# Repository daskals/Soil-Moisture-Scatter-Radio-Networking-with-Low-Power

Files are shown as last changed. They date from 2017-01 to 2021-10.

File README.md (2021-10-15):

# Soil-Moisture-Scatter-Radio-Networking-with-Low-Power
Hardware and Software files of  IEEE publication: Soil Moisture Scatter Radio Networking with Low Power

In this repo, a low-cost (6 Euro per sensor), low-power (in the order of 200 µW per sensor), with high communication range (in the order of 250 meter), scatter radio sensor network is presented, for soil moisture monitoring at multiple locations. The proposed network utilizes analog frequency modulation (FM) in a bistatic network
architecture (i.e., the emitter and reader are not co-located), while
the sensors operate simultaneously, using frequency division
multiple access (FDMA). In contrast to prior art, this work
utilizes an ultra-low cost software-defined radio reader, offers
custom microstrip capacitive sensing with simple calibration, as
well as modulation pulses for each scatter radio sensor with
50% duty cycle; the latter is necessary for scalable network
designs. Overall root mean squared error (RMSE) below 1% is observed, even for ranges of 250 m. This is another small (but concrete) step for the adoption of scatter radio technology as a
key enabling technology for scalable, large-scale, low-power and cost environmental sensor networking.
---

IEEE Xplore: https://ieeexplore.ieee.org/document/7490345/ \
Local: http://www.daskalakispiros.com/files/daskalakis_mtt_2015.pdf

---
**Questions/issues**
Inquiries regarding the scripts provided are cordially welcome.

---
**Citing**

If you use our algorithm, please cite [[1]](https://ieeexplore.ieee.org/document/7490345/).

```bibtex
@article{daskalakis2016soil,
  title={Soil moisture scatter radio networking with low power},
  author={Daskalakis, Spyridon-Nektarios and Assimonis, Stylianos D and Kampianakis, Eleftherios and Bletsas, Aggelos},
  journal={IEEE Transactions on Microwave Theory and Techniques},
  volume={64},
  number={7},
  pages={2338--2346},
  year={2016},
  publisher={IEEE}
}
 
```

[[1]](https://ieeexplore.ieee.org/document/7490345/) S. N. Daskalakis, S.D. Assimonis, E. Kampianakis and A. Bletsas, Soil Moisture Scatter Radio Networking with Low Power, IEEE Transactions on Microwave Theory and Techniques (TMTT), Special Issue on RFID Sensing & Imaging, Vol. 64, No. 7, pp. 2338-2346, July 2016.

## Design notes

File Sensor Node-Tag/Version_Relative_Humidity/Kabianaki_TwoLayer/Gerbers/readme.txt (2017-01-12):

File Description:

GTL: top copper
GBL: bottom copper
GTO: top silkscreen
GTP: top paste
GBO: bottom silkscreen
GTS: top solder mask
GBS: bottom solder mask
DRD: Drill file 1
Dri: Drill file 2

Solder Resist: YES
Silkscreen: NO
Non square: NO
2mm thick: NO
35u Copper: YES
SMD/GOLD: YES
<0.6mm: YES
Clearance < 10mil: YES
Test: NO

Delivery: 7 Days
Quantity: 45

Eleftherios Kampianakis
Tel: 6932702474
Office: 2821037426

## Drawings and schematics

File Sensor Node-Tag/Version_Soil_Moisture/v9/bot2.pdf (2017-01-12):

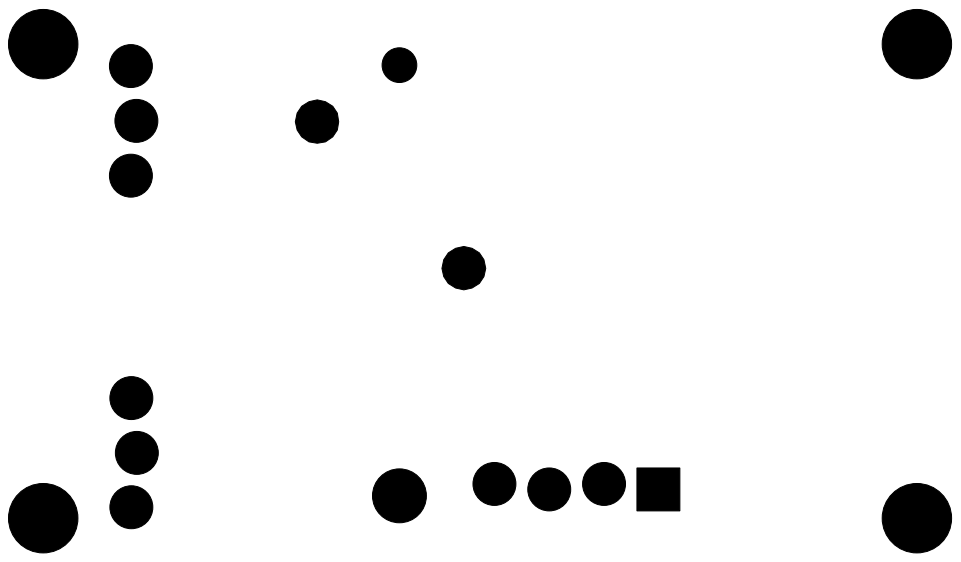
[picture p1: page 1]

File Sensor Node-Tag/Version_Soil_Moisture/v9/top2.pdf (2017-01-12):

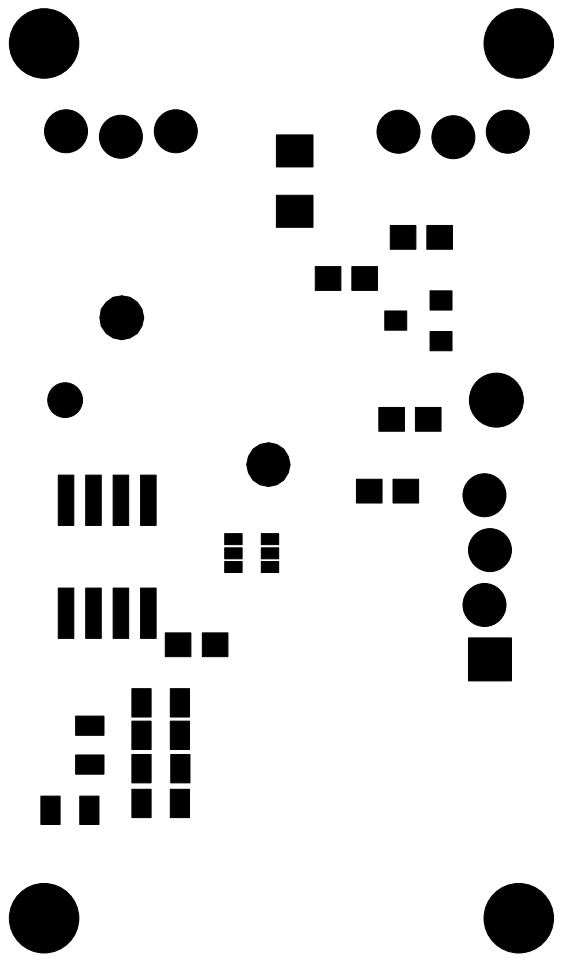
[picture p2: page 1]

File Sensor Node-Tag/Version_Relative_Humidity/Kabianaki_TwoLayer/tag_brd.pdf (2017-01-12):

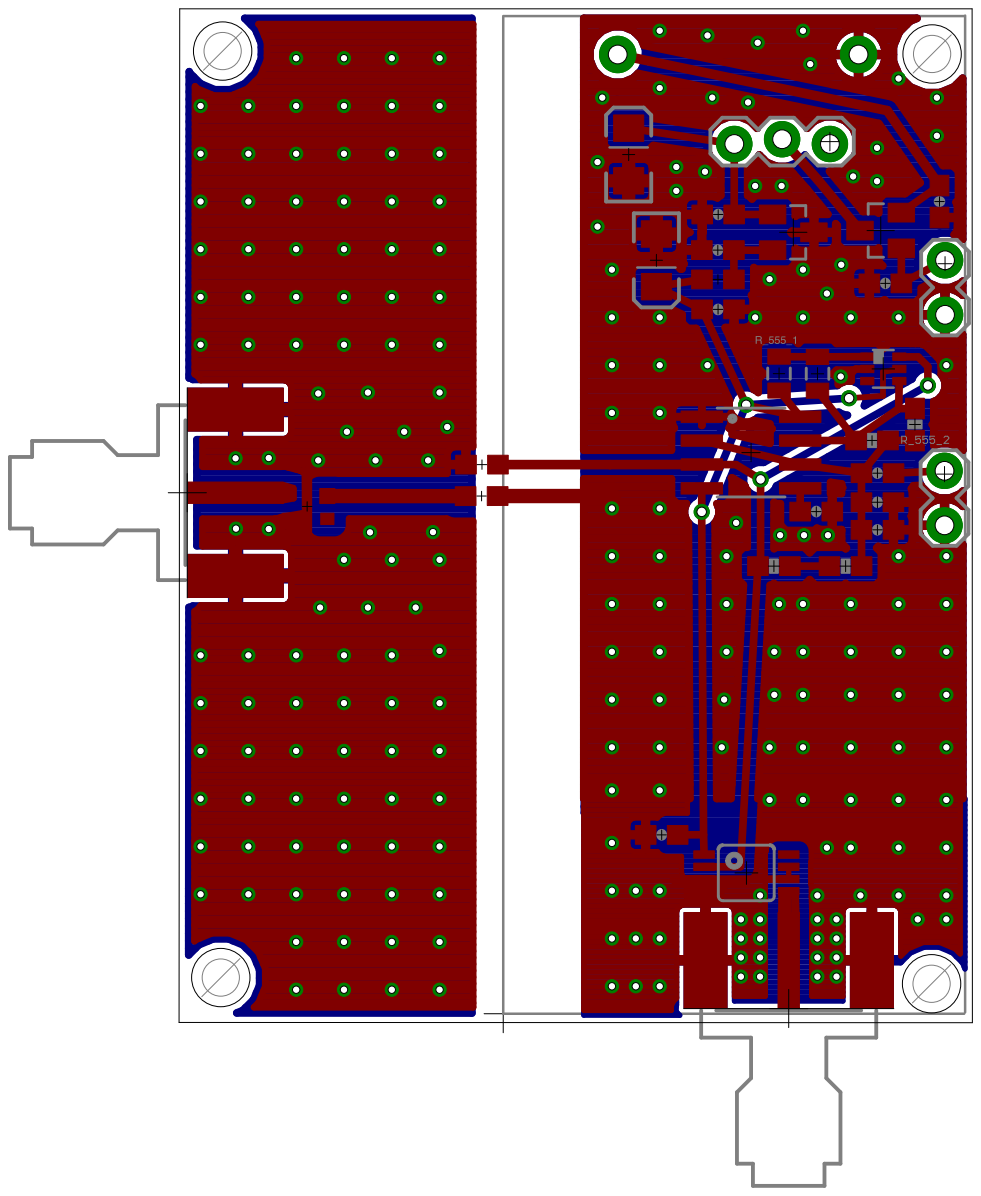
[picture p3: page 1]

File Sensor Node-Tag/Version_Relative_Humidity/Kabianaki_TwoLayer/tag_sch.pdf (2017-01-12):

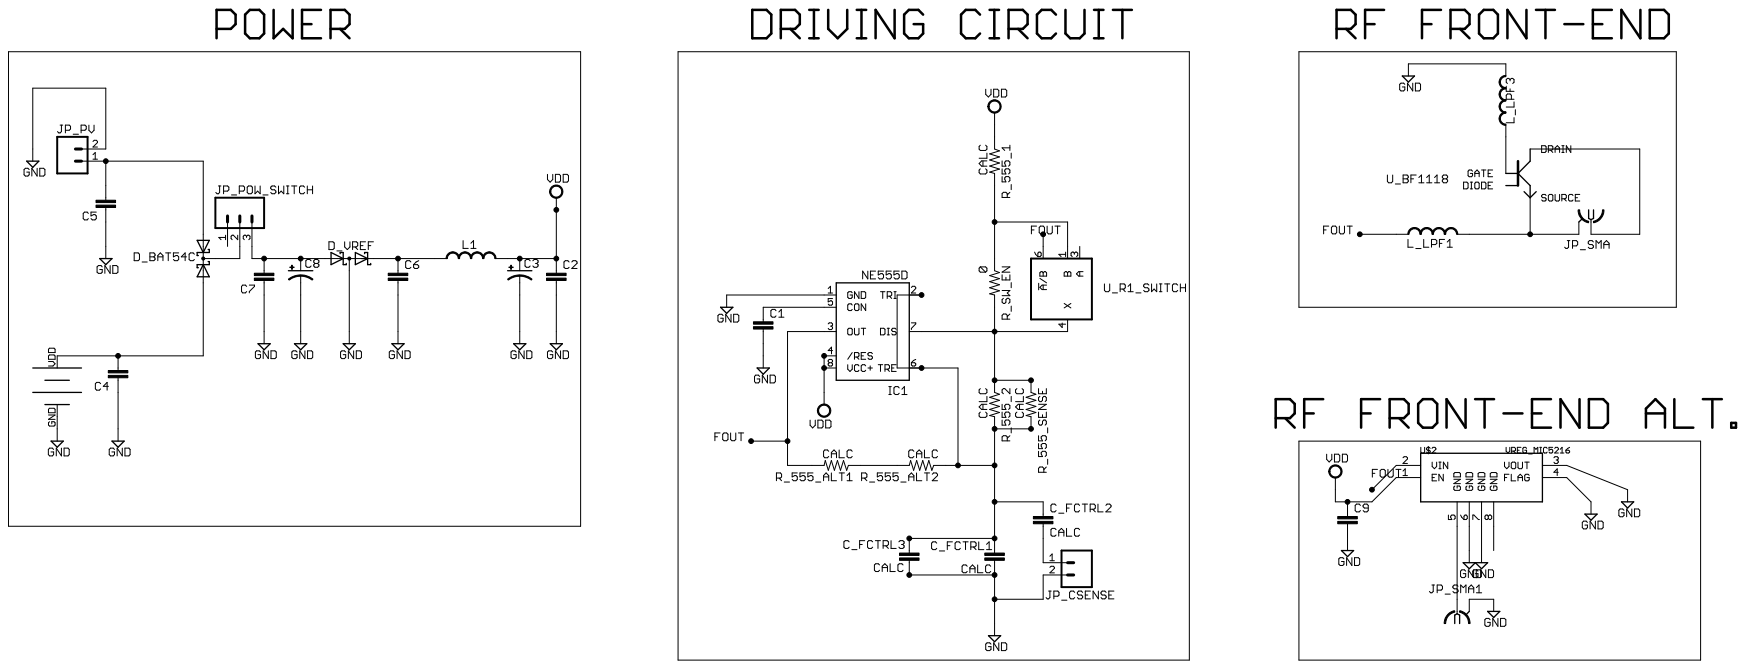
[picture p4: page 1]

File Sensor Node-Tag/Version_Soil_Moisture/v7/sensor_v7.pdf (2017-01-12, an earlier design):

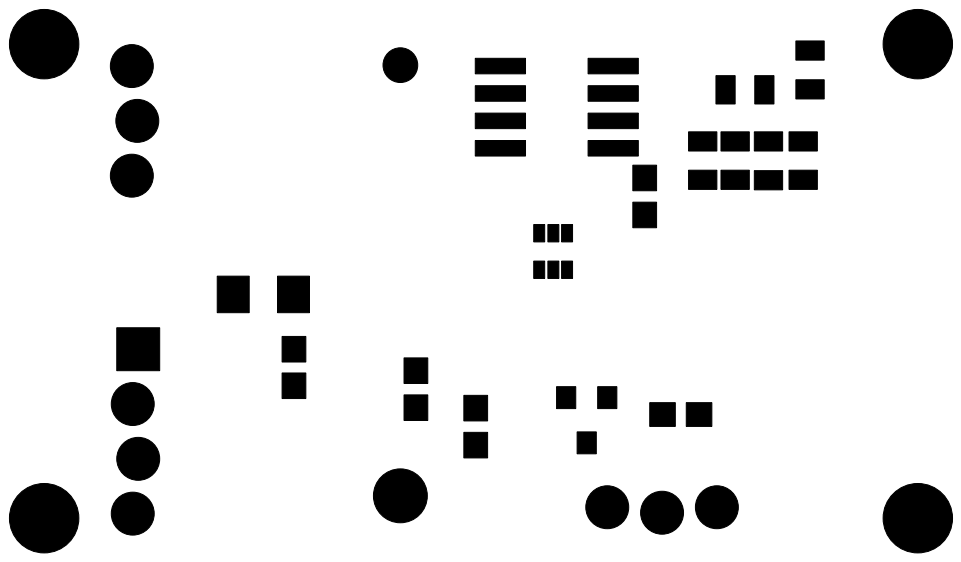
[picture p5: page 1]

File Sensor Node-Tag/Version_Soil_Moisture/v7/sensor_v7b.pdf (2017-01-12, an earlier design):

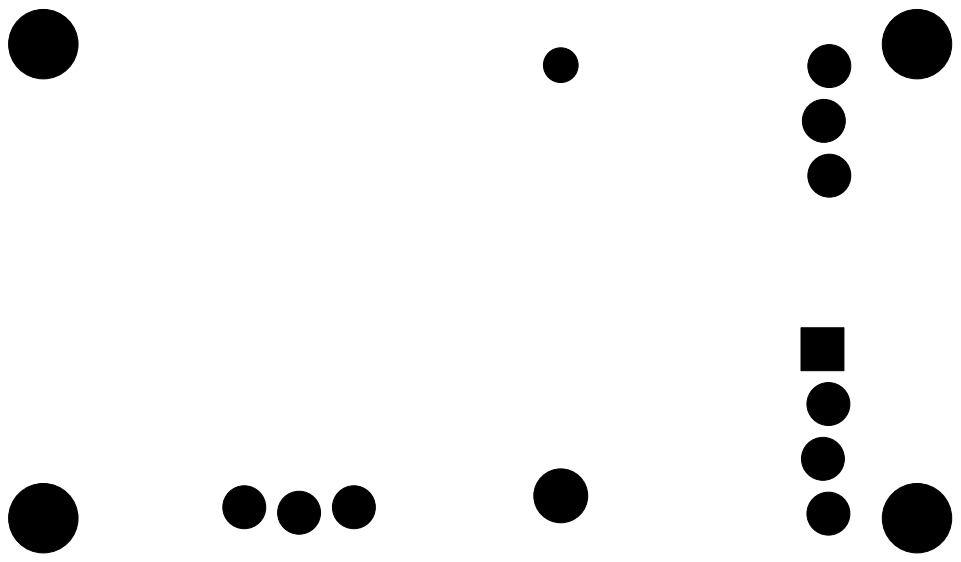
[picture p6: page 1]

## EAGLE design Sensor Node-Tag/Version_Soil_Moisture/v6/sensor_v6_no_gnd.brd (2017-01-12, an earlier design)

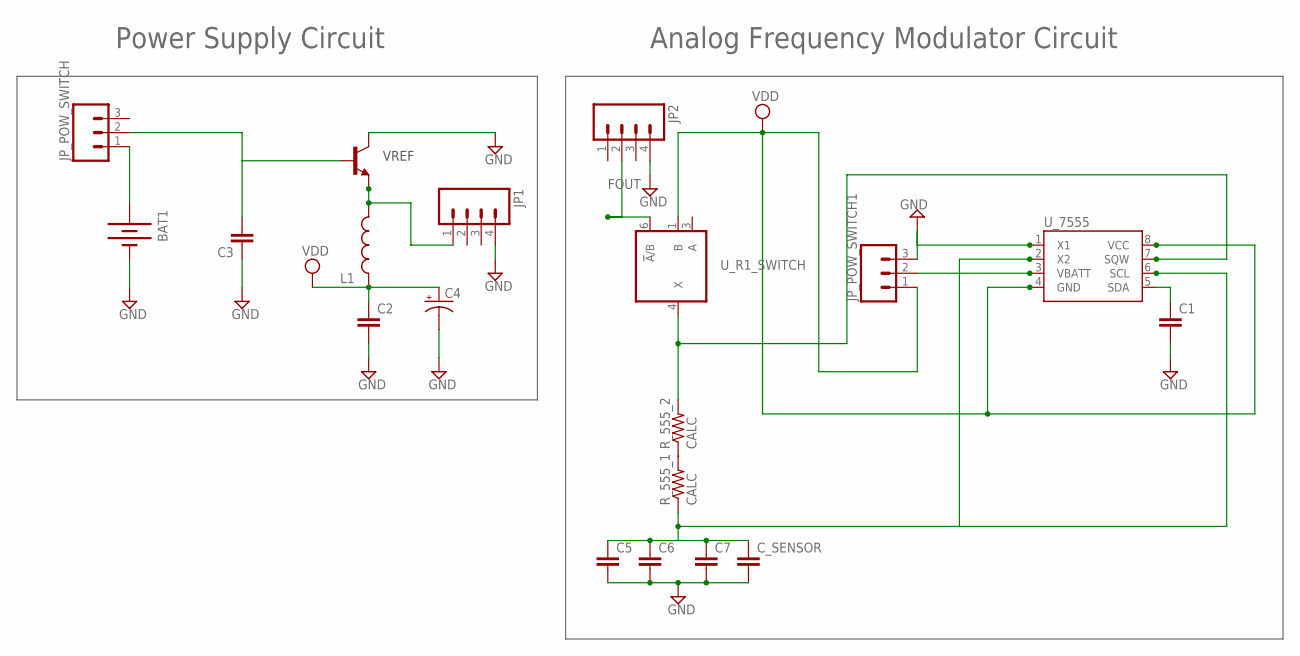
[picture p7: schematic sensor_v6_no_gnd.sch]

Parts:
BAT1: BATTERY20PTH_LAB; BATTCOM_20MM_PTH
C1, C2, C3: CAP0603-CAP; 0603-CAP
C4: CAP_POL1206; EIA3216
C5, C6, C7: CAP0805; 0805
C_SENSOR: CAP0805; 0805
JP1, JP2: M04LOCK; 1X04_LOCK
JP_POW_SWITCH, JP_POW_SWITCH1: M03LOCK; 1X03_LOCK
L1: INDUCTOR0603; 0603
R_555_1, R_555_2: CALC; 0805
U_7555: DS1307SO8; SO08
U_R1_SWITCH: 741G3157DCKR; DCK_R-PDSO-G6
U_VREF: TRANSISTOR_NPNSOT23-3; SOT23-3

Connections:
FOUT: JP2.2, JP_POW_SWITCH1.2, U_7555.3 (VBATT), U_R1_SWITCH.6 (!A!/B)
GND: BAT1.2 (-), C1.2, C2.2, C3.1, C4.C (-), C5.2, C6.2, C7.2, C_SENSOR.2, JP1.4, JP2.4, JP_POW_SWITCH1.3, U_7555.1 (X1), U_R1_SWITCH.2 (GND), U_VREF.3 (C)
unnamed: BAT1.1 (+), JP_POW_SWITCH.1
unnamed: R_555_1.2, R_555_2.1
P2: C5.1, C6.1, C7.1, C_SENSOR.1, R_555_1.1, U_7555.2 (X2), U_7555.6 (SCL)
P5: C1.1, U_7555.5 (SDA)
P7: R_555_2.2, U_7555.7 (SQW), U_R1_SWITCH.4 (X)
VCC: U_R1_SWITCH.5 (VCC)
VDD: C2.1, C4.A (+), JP_POW_SWITCH1.1, L1.1, U_7555.4 (GND), U_7555.8 (VCC), U_R1_SWITCH.1 (B)
VREFIN: C3.2, JP_POW_SWITCH.2, U_VREF.1 (B)
VREFOUT: JP1.1, L1.2, U_VREF.2 (E)

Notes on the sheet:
Power Supply Circuit
Analog Frequency Modulator Circuit
VREF

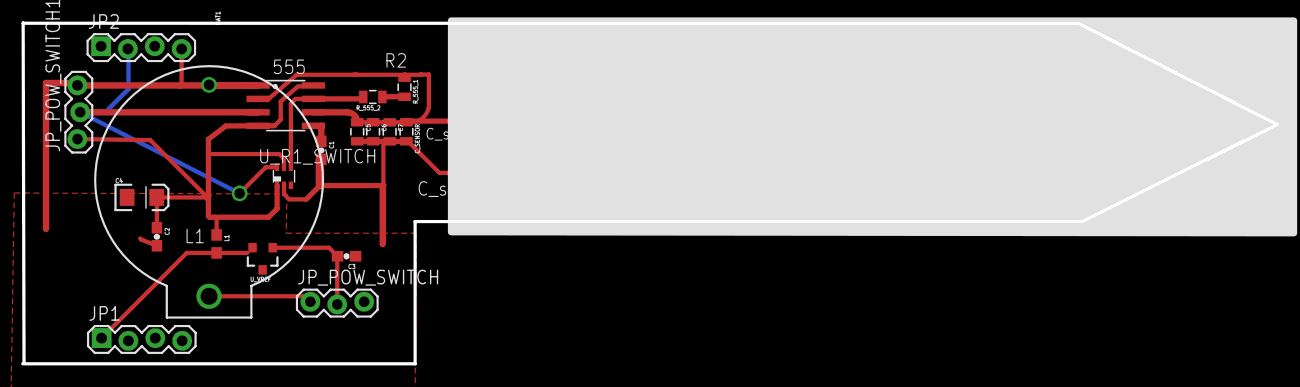
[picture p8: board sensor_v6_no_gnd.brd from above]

Board: 2 copper layers, 118.6 x 32.2 mm, 19 parts (0 on the bottom side), 10 nets.

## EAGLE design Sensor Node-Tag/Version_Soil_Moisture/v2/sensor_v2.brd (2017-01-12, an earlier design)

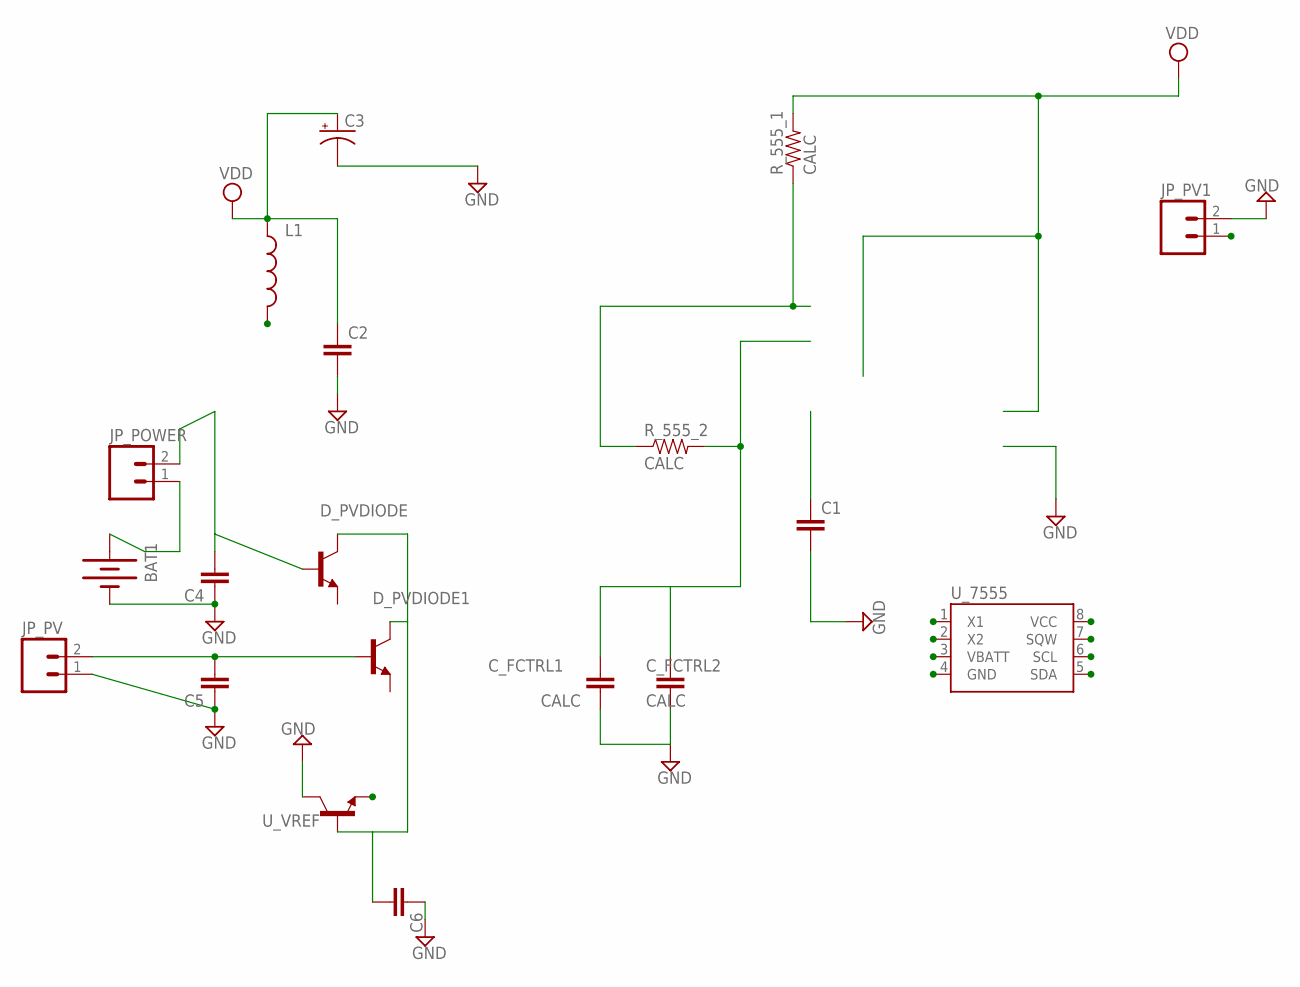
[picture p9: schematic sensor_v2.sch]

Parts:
BAT1: BATTERY20PTH_LAB; BATTCOM_20MM_PTH
C1, C2, C4, C5, C6: CAP0603-CAP; 0603-CAP
C3: CAP_POL1206; EIA3216
C_FCTRL1, C_FCTRL2: CALC; 0603-CAP
D_PVDIODE, D_PVDIODE1: TRANSISTOR_NPNSOT23-3; SOT23-3
JP_POWER: M02LOCK; 1X02_LOCK
JP_PV, JP_PV1: M02LOCK; 1X02_LOCK
L1: INDUCTOR0603; 0603
R_555_1: CALC; 0805
R_555_2: CALC; 0603-RES
U_7555: DS1307SO8; SO08
U_VREF: TRANSISTOR_NPNSOT23-3; SOT23-3

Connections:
FOUT: JP_PV1.1, U_7555.3 (VBATT)
GND: BAT1.2 (-), C1.2, C2.2, C3.C (-), C4.1, C5.1, C6.1, C_FCTRL1.2, C_FCTRL2.2, JP_PV.1, JP_PV1.2, U_7555.1 (X1), U_VREF.3 (C)
unnamed: C5.2, D_PVDIODE1.1 (B), JP_PV.2
unnamed: BAT1.1 (+), JP_POWER.1
unnamed: C4.2, D_PVDIODE.1 (B), JP_POWER.2
P2: C_FCTRL1.1, C_FCTRL2.1, R_555_2.2, U_7555.2 (X2), U_7555.6 (SCL)
P5: C1.1, U_7555.5 (SDA)
P7: R_555_1.1, R_555_2.1, U_7555.7 (SQW)
VDD: C2.1, C3.A (+), L1.1, R_555_1.2, U_7555.4 (GND), U_7555.8 (VCC)
VREFIN: C6.2, D_PVDIODE.3 (C), D_PVDIODE1.3 (C), U_VREF.1 (B)
VREFOUT: L1.2, U_VREF.2 (E)

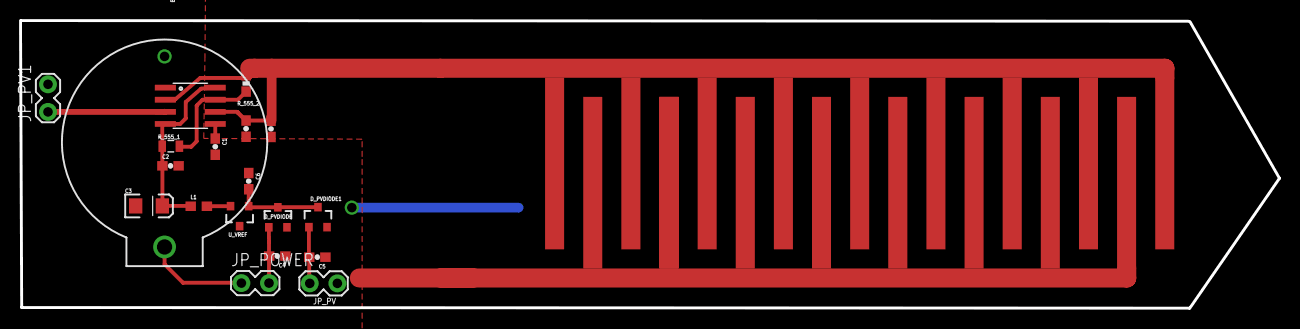
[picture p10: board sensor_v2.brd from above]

Board: 2 copper layers, 132.1 x 30.2 mm, 19 parts (0 on the bottom side), 11 nets.

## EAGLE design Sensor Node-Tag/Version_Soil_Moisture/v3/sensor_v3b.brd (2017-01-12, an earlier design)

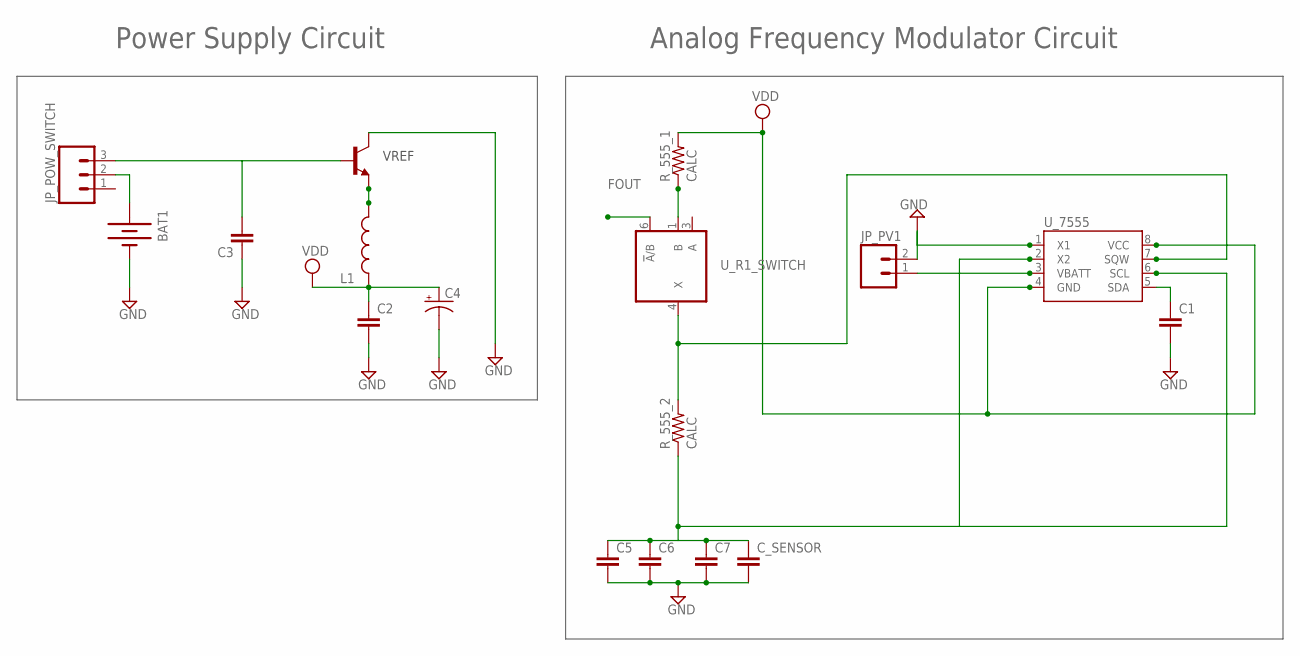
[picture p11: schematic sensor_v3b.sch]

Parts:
BAT1: BATTERY20PTH_LAB; BATTCOM_20MM_PTH
C1, C2, C3: CAP0603-CAP; 0603-CAP
C4: CAP_POL1206; EIA3216
C5, C6, C7: CAP0805; 0805
C_SENSOR: CAP0805; 0805
JP_POW_SWITCH: M03LOCK; 1X03_LOCK
JP_PV1: M02LOCK; 1X02_LOCK
L1: INDUCTOR0603; 0603
R_555_1, R_555_2: CALC; 0805
U_7555: DS1307SO8; SO08
U_R1_SWITCH: 741G3157DCKR; DCK_R-PDSO-G6
U_VREF: TRANSISTOR_NPNSOT23-3; SOT23-3

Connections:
FOUT: JP_PV1.1, U_7555.3 (VBATT), U_R1_SWITCH.6 (!A!/B)
GND: BAT1.2 (-), C1.2, C2.2, C3.1, C4.C (-), C5.2, C6.2, C7.2, C_SENSOR.2, JP_PV1.2, U_7555.1 (X1), U_R1_SWITCH.2 (GND), U_VREF.3 (C)
unnamed: BAT1.1 (+), JP_POW_SWITCH.2
P2: C5.1, C6.1, C7.1, C_SENSOR.1, R_555_2.1, U_7555.2 (X2), U_7555.6 (SCL)
P5: C1.1, U_7555.5 (SDA)
P7: R_555_2.2, U_7555.7 (SQW), U_R1_SWITCH.4 (X)
R1: R_555_1.1, U_R1_SWITCH.1 (B)
VCC: U_R1_SWITCH.5 (VCC)
VDD: C2.1, C4.A (+), L1.1, R_555_1.2, U_7555.4 (GND), U_7555.8 (VCC)
VREFIN: C3.2, JP_POW_SWITCH.3, U_VREF.1 (B)
VREFOUT: L1.2, U_VREF.2 (E)

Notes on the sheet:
Power Supply Circuit
Analog Frequency Modulator Circuit
VREF

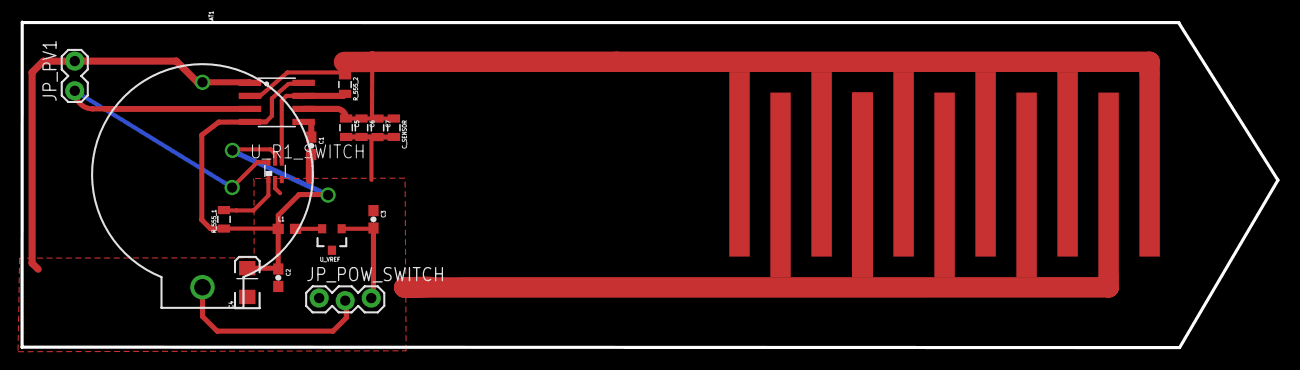
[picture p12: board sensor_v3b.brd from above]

Board: 2 copper layers, 122.5 x 31.8 mm, 17 parts (0 on the bottom side), 10 nets.

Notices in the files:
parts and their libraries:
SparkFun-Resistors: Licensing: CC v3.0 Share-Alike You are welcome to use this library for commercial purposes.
